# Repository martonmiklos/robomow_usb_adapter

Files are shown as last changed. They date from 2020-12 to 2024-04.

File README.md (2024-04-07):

## FT231x based converter to RJ11 connector

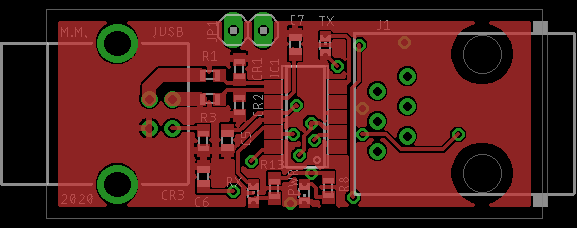
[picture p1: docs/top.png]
Board top view

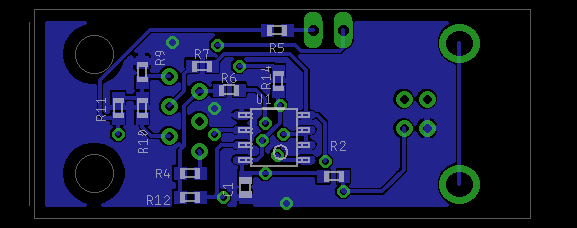
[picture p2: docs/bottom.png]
Board bottom view


Size: 42.44 x 17.78 mm

Drawn in EAGLE 9.x

Warning pozor!! The TX/RX is swapped in the board in the repo, however I stopped using EAGLE and it is not likely, that I am going to fix it.
At some point I might recreate the design in Kicad.

The board has two variants:

### Robomow interface for RM-5xx series 

Normal UART 5V operation for used with Robomow RM toolkit.

You need to invert the both TX and RX lines with the [FT_Prog](https://ftdichip.com/utilities/#ft_prog).

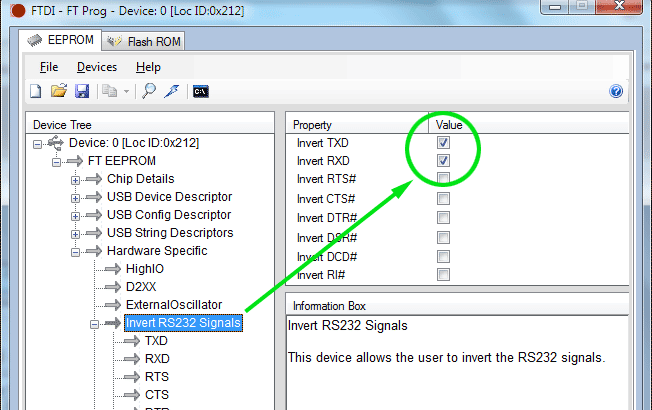
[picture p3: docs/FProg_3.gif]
Invert TX RX in FT Prog


Pinout:
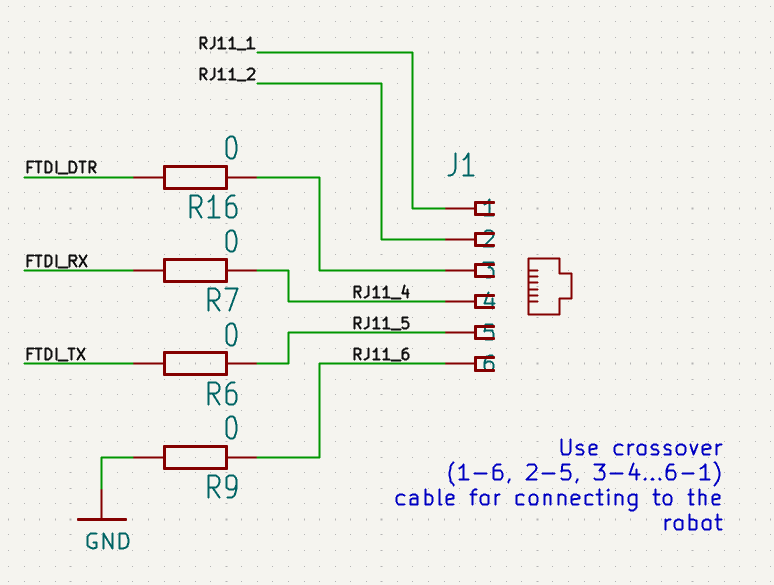
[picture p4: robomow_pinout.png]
Robomow RM series RJ10 pinout


### RS-485 adapter for Sorensen/Ametek DLM series power supplies

For communicating Sorensen DLM series power supplies via RS-485

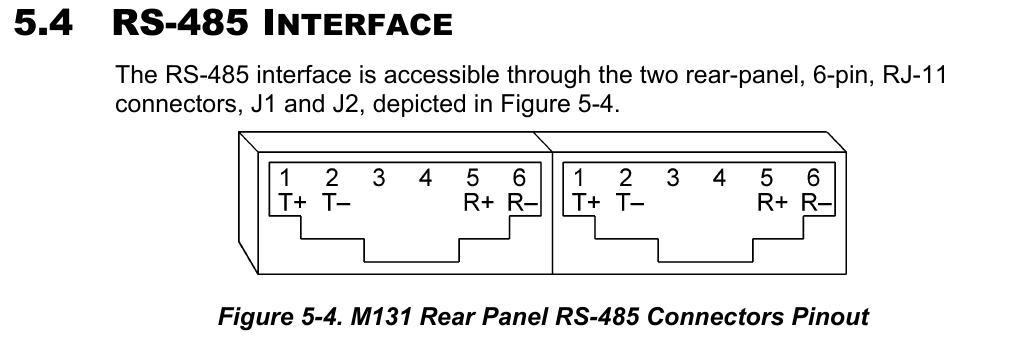
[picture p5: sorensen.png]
Sorensen RS-485 pinout


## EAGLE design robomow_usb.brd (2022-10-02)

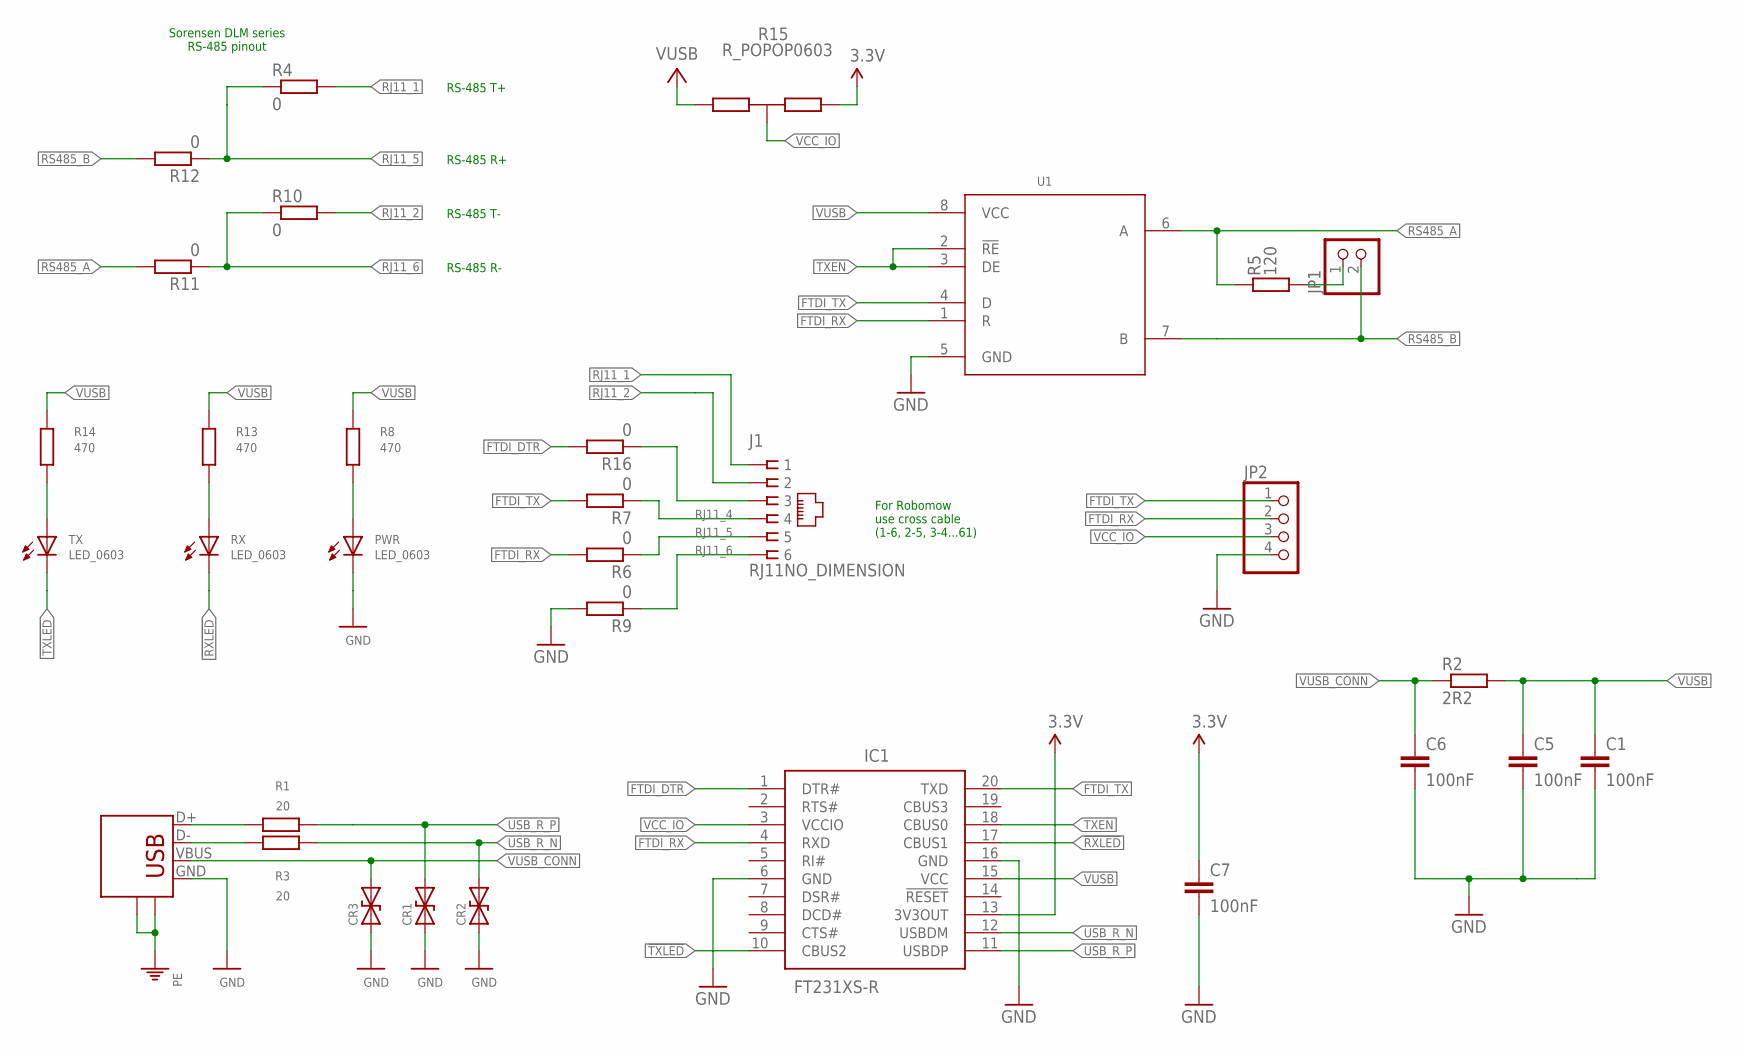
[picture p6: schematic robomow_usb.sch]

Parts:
C1, C5, C6, C7: 100nF; C0603
CR1, CR2, CR3: 0603ESDA2-TR2; 0603
IC1: FT231XS-R; SOP64P599X175-20N
J1: RJ11NO_DIMENSION; RJ11-NO_SHIELD_NO_DIMENSION
JP1: PINHD-1X2; 1X02
JP2: PINHD-1X4; 1X04
JUSB: USBPTH; USB-B-PTH
PWR: LED_0603; LED-603
R1, R3: 20; R0603
R2: 2R2; R0603
R4, R6, R7, R9, R10, R11, R12, R16: 0; R0603
R5: 120; R0603
R8, R13, R14: 470; R0603
R15: R_POPOP0603; 0603_POPOP
RX: LED_0603; LED-603
TX: LED_0603; LED-603
U1: SN65HVD1176; D0008A_N

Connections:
3.3V: C7.1, IC1.13 (3V3OUT), R15.A
!RXLED: IC1.17 (CBUS1), RX.C
!TXLED: IC1.10 (CBUS2), TX.C
FTDI_DTR: IC1.1 (DTR#), R16.2
FTDI_RX: IC1.4 (RXD), JP2.2, R6.2, U1.1 (R)
FTDI_TX: IC1.20 (TXD), JP2.1, R7.2, U1.4 (D)
GND: C1.2, C5.2, C6.2, C7.2, CR1.1, CR2.1, CR3.1, IC1.6 (GND), IC1.16 (GND), JP2.4, JUSB.GND, PWR.C, R9.2, U1.5 (GND)
unnamed: J1.3, R16.1
PE: JUSB.P$1 (SH1), JUSB.P$2 (SH2)
RJ11_1: J1.1, R4.2
RJ11_2: J1.2, R10.2
RJ11_4: J1.4, R7.1
RJ11_5: J1.5, R4.1, R6.1, R12.1
RJ11_6: J1.6, R9.1, R10.1, R11.1
RS485_A: R5.1, R11.2, U1.6 (A)
RS485_B: JP1.2, R12.2, U1.7 (B)
RS485_TERM_ENABLE: JP1.1, R5.2
TXEN: IC1.18 (CBUS0), U1.2 (!RE), U1.3 (DE)
USB_N: JUSB.D-, R3.2
USB_P: JUSB.D+, R1.2
USB_R_N: CR2.2, IC1.12 (USBDM), R3.1
USB_R_P: CR1.2, IC1.11 (USBDP), R1.1
VCC_IO: IC1.3 (VCCIO), JP2.3, R15.COM
VIN_LED_R1: PWR.A, R8.2
VIN_LED_R2: R13.2, RX.A
VIN_LED_R3: R14.2, TX.A
VUSB: C1.1, C5.1, IC1.15 (VCC), R2.2, R8.1, R13.1, R14.1, R15.A1 (B), U1.8 (VCC)
VUSB_CONN: C6.1, CR3.2, JUSB.VBUS, R2.1

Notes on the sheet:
Sorensen DLM series RS-485 pinout
RS-485 T+
RS-485 R+
RS-485 T-
RS-485 R-
For Robomow use cross cable (1-6, 2-5, 3-4...61)

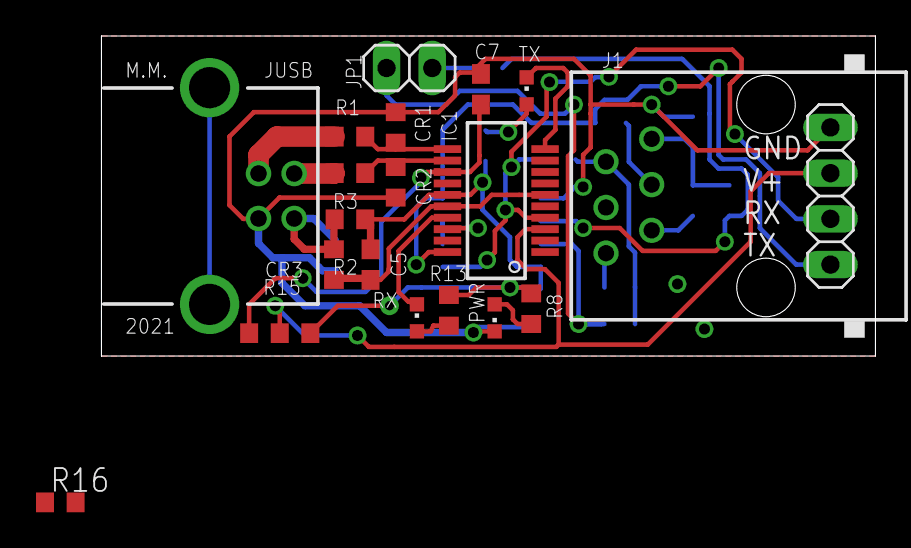
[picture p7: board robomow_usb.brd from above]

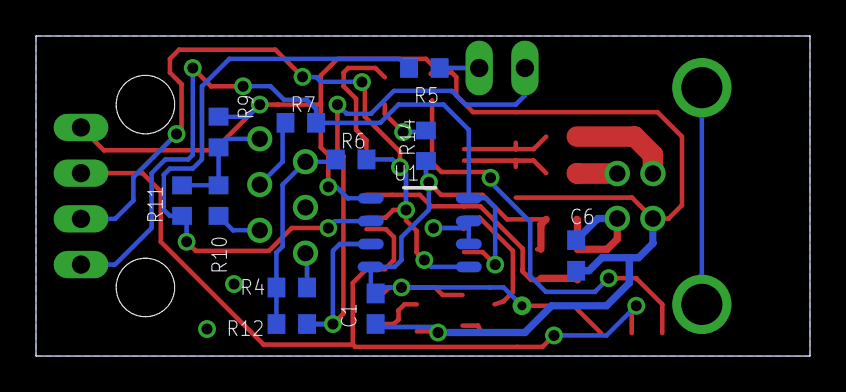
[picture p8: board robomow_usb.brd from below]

Board: 2 copper layers, 43.0 x 17.8 mm, 32 parts (12 on the bottom side), 28 nets.

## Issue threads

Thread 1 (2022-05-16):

rm_toolkit

claudiobosticco, 2022-05-16:
Hello, thanks for the usb adapter, may I ask if you know where I could find the rm_toolkit ?

claudiobosticco, 2022-05-16:
Thank you very much!

martonmiklos, 2022-05-16:
I exchanged the link in the meantime, I posted a newer toolkit link first.

claudiobosticco, 2022-05-16:
downloaded, thank you

claudiobosticco, 2022-05-16:
Actually I need it for a RM400, hope it will work ;-)

martonmiklos, 2022-05-16:
I tested it with an RM-510 which has identical board to the RM400.

What's the plan? Repair or hacking?

martonmiklos, 2022-05-16:
Also note that the pin 4 and 5 (TX/RX)  is swapped on the board, just I was lazy pig fixing it in the design yet.

claudiobosticco, 2022-05-16:
Actually main problem is that the display goes crazy, and shows random changing characters.
If I disconnect the batteries for a while, when I reconnect them it works, then after a while it starts with random characters and gets worse with time. So the first goal is to have a way to access its menus without having to first disconnect batteries. Then if I manage to repair it would be nice.

martonmiklos, 2022-05-16:
Best of luck to the repair!

martonmiklos, 2022-05-18:
> Actually I need it for a RM400, hope it will work ;-)

FYI: I tested it yesterday w. an RM400 board and it works OK.

Closed 2022-05-16.

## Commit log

2020-12-17 Polish routing
    [robomow_usb.brd]
2020-12-19 Added TX RX LEDs
    [robomow_usb.brd, robomow_usb.sch]
2021-05-05 Full pass on DRC (removed stubs)
    [robomow_usb.brd, robomow_usb.sch]
2021-06-20 Fixup input filtering
    [robomow_usb.brd, robomow_usb.sch]
2022-09-30 Pimp readme
    [robomow_usb.brd, robomow_usb.sch]
2022-10-02 Connect DTR (used for boot trigger) for the Robomow mode Thanks Ryan!
    [robomow_usb.brd, robomow_usb.sch]
